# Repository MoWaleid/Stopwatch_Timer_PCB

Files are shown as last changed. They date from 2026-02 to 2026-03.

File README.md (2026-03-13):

# Programmable Logic Timer & Stopwatch (Digital Logic Design)

## Project Overview
A hardware-defined digital timing system engineered using **discrete logic ICs**. This project operates without a microcontroller, utilizing synchronous counters and combinational logic to provide high-precision **Stopwatch (Count-Up)** and **Timer (Countdown)** functionality. The system automates a **220V AC load** via a relay interface upon reaching a user-defined time target.

---

## Core Features
* **Dual Mode:** Stopwatch (00:00 to Target) and Timer (Start Time to 00:00).
* **MM:SS Display:** 4-digit 7-segment output.
* **Hardware Control:** Dedicated tactile buttons for **Set**, **Start/Pause**, and **Reset**.
* **Industrial Interfacing:** Relay module for 220V appliance automation.

---

## Technical Architecture
* **Time Base:** 1Hz pulse generation via a precision **555 Timer** circuit.
* **Logic Core:** Cascaded **74LS192** BCD up/down counters managed by logic gates for state transitions.
* **Display Driver:** **74LS47** BCD-to-7-segment decoders with multiplexing logic.
* **Trigger Logic:** Gate-level detection (AND/NOR) to activate the relay at the target time or zero.
* **Power Stage:** 5V DC logic isolated from the 220V AC output using a relay driver.

---

## Design & Implementation
1.  **Simulation:** Full functional validation in **Proteus** to verify synchronous timing and gate-level logic.
2.  **Schematic Capture:** Professional circuit design in **KiCad**.
3.  **PCB Layout:** Designed a production-ready PCB in **KiCad**, implementing specific trace widths for high-voltage safety and signal integrity.

---

## Components List
* **Counters:** 74LS192 BCD Counters.
* **Decoders:** 74LS47 BCD-to-7-Segment.
* **Logic Gates:** 74LS08 (AND), 74LS32 (OR), 74LS04 (NOT).
* **Timer:** NE555.
* **Output:** 5V Relay, LED.

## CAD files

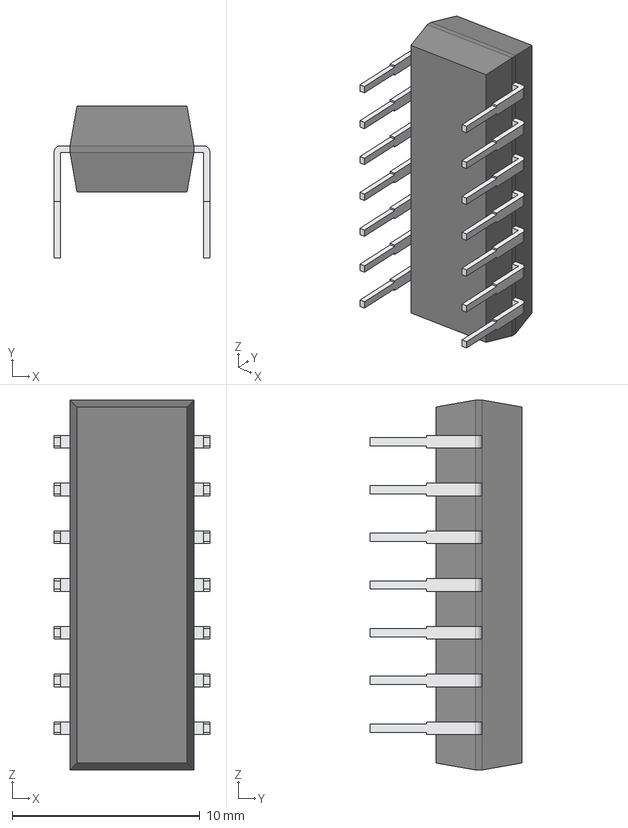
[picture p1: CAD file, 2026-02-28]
3D Models/SN74HC32N.step
8.29 x 8.08 x 19.7 mm
Body001 (Mirror #1) x 8

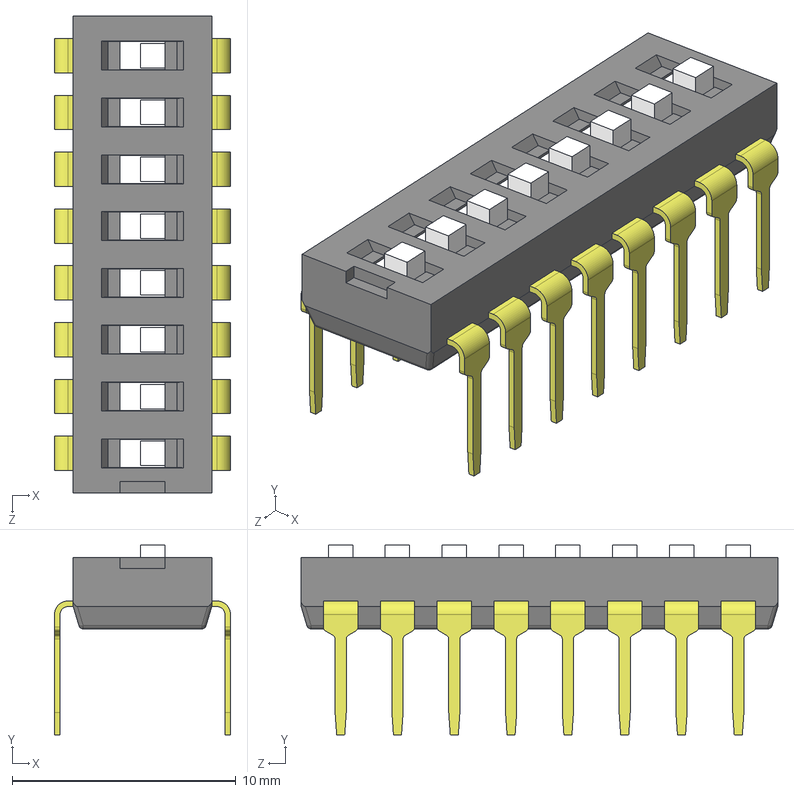
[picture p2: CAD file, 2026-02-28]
3D Models/DS04-254-1L-08BK.step
7.87 x 8.49 x 21.3 mm

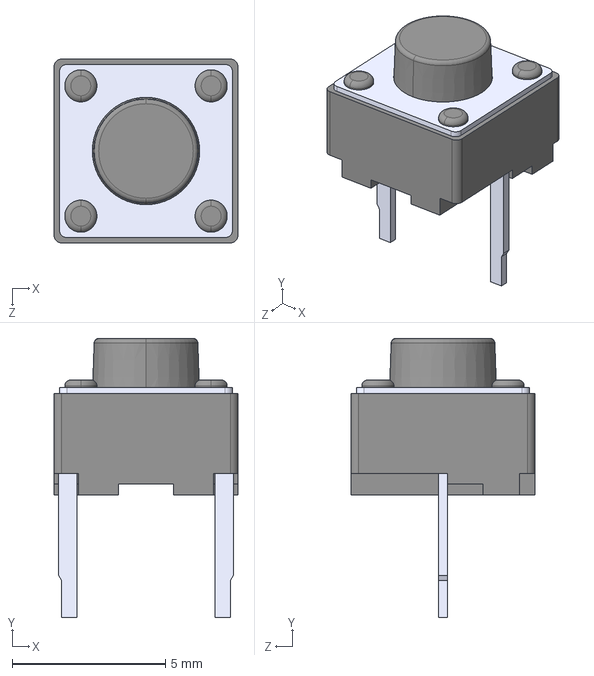
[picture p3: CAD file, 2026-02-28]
3D Models/BUTT-2.step
6.00 x 9.10 x 6.00 mm

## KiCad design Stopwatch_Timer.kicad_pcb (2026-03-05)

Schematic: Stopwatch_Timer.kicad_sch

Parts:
AFF1, AFF2, AFF3, AFF4: LTS-6960HR; 7SegmentLED_LTS6760_LTS6780
C1: 10u; C_Radial_D5.0mm_H11.0mm_P2.00mm
C2: 10n; C_Disc_D5.0mm_W2.5mm_P5.00mm
J3: Conn_01x06_Socket; PinSocket_1x06_P2.54mm_Vertical
MT1: 74LS192; DIP-16_W7.62mm_Socket
MU1: 74LS192; DIP-16_W7.62mm_Socket
R1: 1k; R_Axial_DIN0207_L6.3mm_D2.5mm_P7.62mm_Horizontal
R1_Timer1, R2_Timer1: 22k; R_Axial_DIN0207_L6.3mm_D2.5mm_P7.62mm_Horizontal
R3, R32, R33, R34, R35, R36, R37, R38, R40, R41, R42, R43, R44, R45, R46, R47: 330; R_Axial_DIN0207_L6.3mm_D2.5mm_P10.16mm_Horizontal
R3_Timer1, R4_Timer1, R5_Timer1, R6_Timer1, R50: 10k; R_Axial_DIN0207_L6.3mm_D2.5mm_P7.62mm_Horizontal
R4, R5, R6, R7, R8, R9, R10, R11, R12, R13, R14, R15, R16, R17, R18, R19, R20, R21, R22, R23, R24, R25, R26, R27, R28, R29, R30, R31, R39, R49: 330; R_Axial_DIN0207_L6.3mm_D2.5mm_P7.62mm_Horizontal
R_Mode1: 330; R_Axial_DIN0207_L6.3mm_D2.5mm_P7.62mm_Horizontal
S3, S4, S5: BUTT-2; SW_BUTT-2; PARTREV N/A
ST1: 74LS192; DIP-16_W7.62mm_Socket
SU1: 74LS192; DIP-16_W7.62mm_Socket
SW1, SW3: SW_DIP_x08; SW_DIP_SPSTx08_Slide_6.7x21.88mm_W7.62mm_P2.54mm_LowProfile
SW2: SW_DIP_x04; SW_DIP_SPSTx04_Slide_6.7x11.72mm_W7.62mm_P2.54mm_LowProfile
U1: NE555P; DIP-8_W7.62mm_Socket
U4, U6, U7, U9: 74LS47; DIP-16_W7.62mm_Socket
U10: 74LS157; DIP-16_W7.62mm_Socket
U11, U13: SN74HC04N; DIP-14_W7.62mm_Socket
U12, U21: CD4075BE; DIP-14_W7.62mm_Socket; DigiKey_Part_Number 296-2065-5-ND
U18, U20, U23: SN74HC32N; DIP-14_W7.62mm_Socket
U19, U24: SN74HC08N; DIP-14_W7.62mm_Socket
U22: CD4023BE; DIP-14_W7.62mm_Socket

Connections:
+5V: AFF1.3 (C.A.), AFF1.5 (DP), AFF1.8 (C.A.), AFF2.3 (C.A.), AFF2.5 (DP), AFF2.8 (C.A.), AFF3.3 (C.A.), AFF3.5 (DP), AFF3.8 (C.A.), AFF4.3 (C.A.), AFF4.5 (DP), AFF4.8 (C.A.), J3.1, J3.4, MT1.16 (VCC), MU1.16 (VCC), R1.2, R50.1, S4.1, S5.2, ST1.16 (VCC), SU1.16 (VCC), SW1.1, SW1.2, SW1.3, SW1.4, SW1.5, SW1.6, SW1.7, SW1.8, SW2.1, SW3.1, SW3.2, SW3.3, SW3.4, SW3.5, SW3.6, SW3.7, SW3.8, U1.4 (~RST), U1.8 (VCC), U4.3 (LT), U4.4 (BI), U4.5 (RBI), U4.16 (VCC), U6.3 (LT), U6.4 (BI), U6.5 (RBI), U6.16 (VCC), U7.3 (LT), U7.4 (BI), U7.5 (RBI), U7.16 (VCC), U9.3 (LT), U9.4 (BI), U9.5 (RBI), U9.16 (VCC), U10.3 (I1a), U10.10 (I1c), U10.16 (VCC), U11.14 (VCC), U12.14 (VDD), U13.14 (VCC), U18.14 (VCC), U19.14 (VCC), U20.14 (VCC), U21.14 (VDD), U22.8 (C), U22.14 (VDD), U24.14 (VCC)
GND: C1.2, C2.2, J3.2, J3.6, MT1.8 (GND), MU1.8 (GND), R3.2, R32.2, R33.2, R34.2, R35.2, R36.2, R37.2, R38.2, R40.2, R41.2, R42.2, R43.2, R44.2, R45.2, R46.2, R47.2, R49.2, R_Mode1.2, S3.1, ST1.8 (GND), SU1.8 (GND), U1.1 (GND), U4.8 (GND), U6.8 (GND), U7.8 (GND), U9.8 (GND), U10.6 (I1b), U10.8 (GND), U10.13 (I1d), U10.15 (E), U11.7 (GND), U12.7 (VSS), U13.7 (GND), U18.7 (GND), U19.7 (GND), U20.7 (GND), U21.7 (VSS), U22.7 (VSS), U23.7 (GND), U24.7 (GND), U24.12 (4A), U24.13 (4B)
unnamed: AFF1.7 (a), R4.2
unnamed: AFF1.6 (b), R5.2
unnamed: AFF1.4 (c), R6.2
unnamed: AFF1.2 (d), R7.2
unnamed: AFF1.1 (e), R8.2
unnamed: AFF1.9 (f), R9.2
unnamed: AFF1.10 (g), R10.2
unnamed: AFF2.7 (a), R11.2
unnamed: AFF2.6 (b), R12.2
unnamed: AFF2.4 (c), R13.2
unnamed: AFF2.2 (d), R14.2
unnamed: AFF2.1 (e), R15.2
unnamed: AFF2.9 (f), R16.2
unnamed: AFF2.10 (g), R17.2
unnamed: AFF3.7 (a), R18.2
unnamed: AFF3.6 (b), R19.2
unnamed: AFF3.4 (c), R20.2
unnamed: AFF3.2 (d), R21.2
unnamed: AFF3.1 (e), R22.2
unnamed: AFF3.9 (f), R23.2
unnamed: AFF3.10 (g), R24.2
unnamed: AFF4.7 (a), R25.2
unnamed: AFF4.6 (b), R26.2
unnamed: AFF4.4 (c), R27.2
unnamed: AFF4.2 (d), R28.2
unnamed: AFF4.1 (e), R29.2
unnamed: AFF4.9 (f), R30.2
unnamed: AFF4.10 (g), R31.2
unnamed: J3.5, U13.13 (6A), U18.8 (3Y)
unnamed: MT1.15 (A), R43.1, SW3.13
unnamed: MT1.1 (B), R42.1, SW3.14
unnamed: MT1.10 (C), R41.1, SW3.15
unnamed: MT1.14 (CLR), MU1.14 (CLR), SU1.14 (CLR), U20.8 (3Y), U23.2 (1B)
unnamed: MT1.9 (D), R40.1, SW3.16
unnamed: MT1.4 (DOWN), MU1.13 (~BO)
unnamed: MT1.3 (QA), U6.7 (A), U21.1 (A)
unnamed: MT1.2 (QB), U6.1 (B), U21.2 (B)
unnamed: MT1.6 (QC), U6.2 (C), U21.8 (C)
unnamed: MT1.7 (QD), U6.6 (D), U21.3 (D)
unnamed: MT1.5 (UP), MU1.12 (~CO)
unnamed: MT1.11 (~LOAD), MU1.11 (~LOAD), R50.2, S3.2, SU1.11 (~LOAD), U19.1 (1A), U24.1 (1A)
unnamed: MU1.15 (A), R47.1, SW3.9
unnamed: MU1.1 (B), R46.1, SW3.10
unnamed: MU1.10 (C), R45.1, SW3.11
unnamed: MU1.9 (D), R44.1, SW3.12
unnamed: MU1.4 (DOWN), ST1.13 (~BO)
unnamed: MU1.3 (QA), U4.7 (A), U21.4 (E)
unnamed: MU1.2 (QB), U4.1 (B), U21.5 (F)
unnamed: MU1.6 (QC), U4.2 (C), U21.13 (G)
unnamed: MU1.7 (QD), U4.6 (D), U21.12 (H)
unnamed: MU1.5 (UP), U11.4 (2Y)
unnamed: R1_Timer1.2, R2_Timer1.1
unnamed: R2_Timer1.2, R3_Timer1.1
unnamed: R3_Timer1.2, R4_Timer1.1
unnamed: R4_Timer1.2, R5_Timer1.1
unnamed: R5_Timer1.2, R6_Timer1.1
unnamed: ST1.15 (A), U10.4 (Za)
unnamed: ST1.1 (B), U10.7 (Zb)
unnamed: ST1.10 (C), U10.9 (Zc)
unnamed: ST1.14 (CLR), U23.3 (1Y)
unnamed: ST1.9 (D), U10.12 (Zd)
unnamed: ST1.4 (DOWN), SU1.13 (~BO)
unnamed: ST1.3 (QA), U7.7 (A), U21.11 (I), U22.1 (A)
unnamed: ST1.2 (QB), U7.1 (B), U12.1 (A), U24.9 (3A)
unnamed: ST1.6 (QC), U7.2 (C), U12.2 (B), U24.10 (3B)
unnamed: ST1.7 (QD), U7.6 (D), U12.8 (C), U22.2 (B)
unnamed: ST1.5 (UP), SU1.12 (~CO)
unnamed: ST1.11 (~LOAD), U24.3 (1Y)
unnamed: R38.1, SU1.15 (A), SW1.9
unnamed: R37.1, SU1.1 (B), SW1.10
unnamed: R36.1, SU1.10 (C), SW1.11
unnamed: R35.1, SU1.9 (D), SW1.12
unnamed: SU1.4 (DOWN), U20.6 (2Y)
unnamed: SU1.3 (QA), U9.7 (A), U12.3 (D)
unnamed: SU1.2 (QB), U9.1 (B), U12.4 (E)
unnamed: SU1.6 (QC), U9.2 (C), U12.5 (F)
unnamed: SU1.7 (QD), U9.6 (D), U12.13 (G)
unnamed: SU1.5 (UP), U20.3 (1Y)
unnamed: C2.1, U1.5 (CONT)
unnamed: R1.1, R1_Timer1.1, U1.7 (DISCH)
unnamed: R39.1, U1.3 (OUT)
unnamed: C1.1, R6_Timer1.2, U1.2 (TRIG), U1.6 (THRES)
unnamed: R11.1, U4.13 (a)
unnamed: R12.1, U4.12 (b)
unnamed: R13.1, U4.11 (c)
unnamed: R14.1, U4.10 (d)
unnamed: R15.1, U4.9 (e)
unnamed: R16.1, U4.15 (f)
unnamed: R17.1, U4.14 (g)
unnamed: R4.1, U6.13 (a)
unnamed: R5.1, U6.12 (b)
unnamed: R6.1, U6.11 (c)
unnamed: R7.1, U6.10 (d)
unnamed: R8.1, U6.9 (e)
unnamed: R9.1, U6.15 (f)
unnamed: R10.1, U6.14 (g)
unnamed: R18.1, U7.13 (a)
unnamed: R19.1, U7.12 (b)
unnamed: R20.1, U7.11 (c)
unnamed: R21.1, U7.10 (d)
unnamed: R22.1, U7.9 (e)
unnamed: R23.1, U7.15 (f)
unnamed: R24.1, U7.14 (g)
unnamed: R25.1, U9.13 (a)
unnamed: R26.1, U9.12 (b)
unnamed: R27.1, U9.11 (c)
unnamed: R28.1, U9.10 (d)
unnamed: R29.1, U9.9 (e)
unnamed: R30.1, U9.15 (f)
unnamed: R31.1, U9.14 (g)
unnamed: R34.1, SW1.13, U10.2 (I0a)
unnamed: R33.1, SW1.14, U10.5 (I0b)
unnamed: R32.1, SW1.15, U10.11 (I0c)
unnamed: R3.1, SW1.16, U10.14 (I0d)
unnamed: U10.1 (S), U11.2 (1Y)
unnamed: U11.1 (1A), U22.9 (J*~(A.B.C)), U24.2 (1B)
unnamed: U11.3 (2A), U23.1 (1A), U24.6 (2Y)
unnamed: R_Mode1.1, SW2.8, U11.5 (3A), U13.1 (1A), U19.5 (2B), U20.2 (1B)
unnamed: U11.6 (3Y), U24.4 (2A)
unnamed: U12.9 (J*A+B+C), U12.12 (H)
unnamed: U12.6 (K*D+E+F), U12.11 (I)
unnamed: U12.10 (L*G+H+I), U18.5 (2B)
unnamed: U13.2 (1Y), U20.5 (2B)
unnamed: U13.12 (6Y), U19.2 (1B)
unnamed: U18.1 (1A), U21.9 (J*A+B+C)
unnamed: U18.2 (1B), U21.6 (K*D+E+F)
unnamed: U18.3 (1Y), U18.9 (3A)
unnamed: U18.4 (2A), U21.10 (L*G+H+I)
unnamed: U18.6 (2Y), U18.10 (3B)
unnamed: U19.3 (1Y), U19.4 (2A)
unnamed: U19.6 (2Y), U20.10 (3B)
unnamed: R39.2, S5.1, U20.1 (1A), U20.4 (2A)
unnamed: R49.1, S4.2, U20.9 (3A)
unnamed: U24.5 (2B), U24.8 (3Y)

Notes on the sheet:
Not Gate
Big Or Output
Count Up/Down
NAND Gate
LSB
Output for MR
Output of triple And
Up Or
Set Button
Clock
Not of Count/Up Down
Or Output
Mux
Big And Output
NAND OF MSB and LSB
Count Up/DOwn
Middle Bits
Down Or
MSB
Not of Big Or Output
Not of NAND
Not of Count Up/Down
Start/Pause
Not Of Big Or
Output of triple AND
555 Timer
Output of Middle Bits
Set Button
Not output of triple AND
2-Input AND
PL input of second counter
Their Output
AND
Global Reset
Count UP/Down
Or Gate

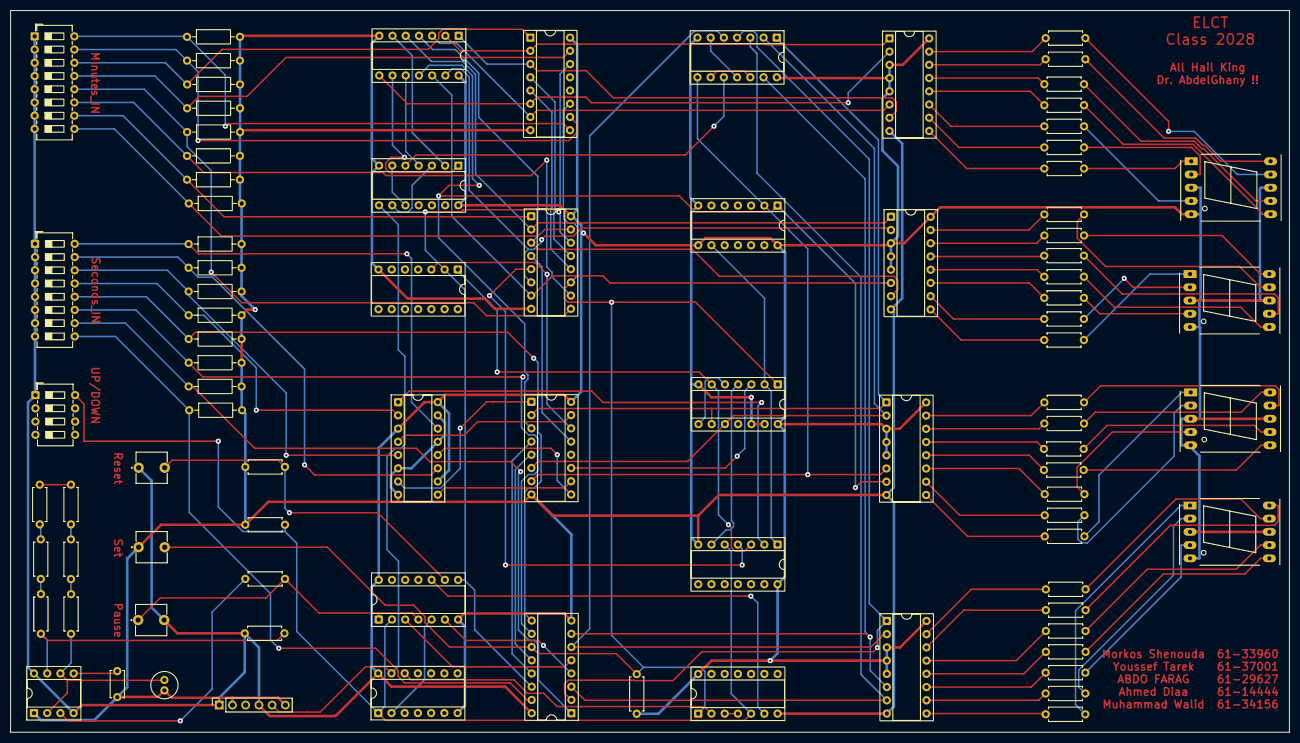
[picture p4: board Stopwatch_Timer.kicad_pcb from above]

Board: 2 copper layers, 245.6 x 138.6 mm, 88 parts (0 on the bottom side), 136 nets.

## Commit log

2026-02-28 initiated the project
    [BUTT-2.step, CD4023BE.step, CD4075BE.step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]
2026-02-28 Test parallel work
    [Stopwatch_Timer.kicad_pcb]
2026-03-01 Done part of the routing
    [Stopwatch_Timer.kicad_pcb, Stopwatch_Timer.kicad_sch]
2026-03-02 Final PCB design
    [Stopwatch_Timer-B_Cu.gbl, Stopwatch_Timer-B_Mask.gbs, Stopwatch_Timer-B_Paste.gbp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]
2026-03-03 Finalized PCB design
    [Stopwatch_Timer-B_Cu.gbl, Stopwatch_Timer-B_Mask.gbs, Stopwatch_Timer-B_Paste.gbp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]
2026-03-05 replaced silkscreen text with copper text
    [Stopwatch_Timer-B_Cu.gbl, Stopwatch_Timer-B_Mask.gbs, Stopwatch_Timer-B_Paste.gbp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]
2026-03-11 Add README for Programmable Logic Timer & Stopwatch
    Added detailed project overview, core features, technical architecture, design and implementation steps, and components list for the Programmable Logic Timer & Stopwatch.
